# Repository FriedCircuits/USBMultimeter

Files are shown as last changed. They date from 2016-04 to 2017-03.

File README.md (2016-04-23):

USB Multimeter
===============================================

This repo will contain all the design and firmware code for the USB Multimeter as development progresses.

Currently the project is just a add-on board for the STM32F429 Discovery board. See the subfolder for details. 

More information at
[https://hackaday.io/friedcircuits](https://hackaday.io/friedcircuits)

License: All source code and designs are released under 

Creative Commons ShareAlike 

CC BY-SA



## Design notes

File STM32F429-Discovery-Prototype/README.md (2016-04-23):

Prototype Using the STM32F429 Discovery Board
===============================================

This is a add-on board that can be press-fit to the bottom of the STM32F429 Discovery board 
to allow firmware development till I can design the prototype hardware. 

More information at
[https://hackaday.io/friedcircuits](https://hackaday.io/friedcircuits)

License: All source code and designs are released under 

Creative Commons ShareAlike 

CC BY-SA



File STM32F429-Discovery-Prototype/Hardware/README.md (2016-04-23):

Hardware for USB Multimeter STM32F429 Add-on Board
======================================================

Warning: The TX/RX pairs need to be swapped for this design to work.

I only made one spin of this board and ended up swapping the pairs with some bodge wires.

Also there is an I2C address conflict with the INA219's. I forgot to set the 2nd one to another address.

This is here just as a referance as this was a one off board.

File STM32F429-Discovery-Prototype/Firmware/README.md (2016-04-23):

Prototype Using the STM32F429 Discovery Board
===============================================

This the firmware for the Discovery Board. 

Written is C using Embitz IDE.

The firmware is built on top of ChibiOS which has excellent support for STM32.

The graphics engine is handled by uGFX. 

This code is highly alpha with many bugs and crashes. It is a work in progress. 

Eventually this will be turned into the firmware for the final hardare prototype. 

License: All source code and designs are released under 

Creative Commons ShareAlike 

CC BY-SA



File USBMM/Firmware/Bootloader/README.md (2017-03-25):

#USB Multimeter Bootloader
Posted for testing during development
Do not use since USB VID/PID needs to be changed.

Based on fork from 
[https://github.com/watterott/SAM-BAR](https://github.com/watterott/SAM-BAR)

# SAM-BAR
SAM-BAR (**S**mart **A**tmel **M**icrocontroller **B**oot **A**ssistant **R**eloaded) is an USB bootloader for Atmel/Microchip SAM D21 devices (ARM Cortex-M0+).
It is based on the following bootloaders:
* [SAM-BA (AppNote AT07175) by Atmel/Microchip (www.atmel.com)](http://www.atmel.com/images/Atmel-42366-SAM-BA-Bootloader-for-SAM-D21_ApplicationNote_AT07175.zip)
* [Arduino Zero Bootloader by Arduino LLC (www.arduino.cc)](https://github.com/arduino/ArduinoCore-samd/tree/master/bootloaders/zero)
* [SAMD-MSD-Bootloader by Justin Mattair (www.mattairtech.com)](https://github.com/mattairtech/SAMD-MSD-Bootloader)

## Features
* SAM-BA and Arduino Zero compatible Bootloader (USB CDC/VCP)
* Mass-Storage-Device Bootloader (USB MSD/MSC)
* Fits in 16KB (user program start at 0x4000)

## Software
* [Bootloader Source Code](https://github.com/friedcircuits/USBMultimeter/tree/master/USBMM/Firmware/Bootloader/bootloader)
* [Board Support Package for Arduino IDE](https://github.com/friedcircuits/USBMultimeter/tree/master/USBMM/Firmware/Bootloader/arduino)

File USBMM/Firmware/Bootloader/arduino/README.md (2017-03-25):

#USB Multimeter Bootloader
Posted for testing during development
Do not use since USB VID/PID needs to be changed.

# Board Support Package
Board Support Package for [Arduino IDE v1.6+](https://www.arduino.cc/en/Main/Software) with Arduino SAMD Boards v1.6.10+

## Installation

Add the following URL to the Arduino Boards Manager (*File->Preferences*):
```
https://github.com/FriedCircuits/USBMultimeter/raw/master/USBMM/Firmware/Bootloader/arduino/package_usbmm_index.json
```
Then open the Arduino Boards Manager (*Tools->Boards->Boards Manager*) and install the 
**Arduino SAMD Boards** and **SAMD (ARM Cortex-M0+) Boards with SAM-BAR**.

## Bootloader

The bootloader can be activated via the Arduino IDE or by doing two reset in 0.5s (double pressing reset switch).

When the bootloader is active then a new program can be loaded via the Arduino IDE and the serial port or via the mass storage device.
For the mass storage device delete the file ```FLASH.BIN``` and then copy a new binary file ```FLASH.BIN``` to the drive.
After the copy process is finished, do a reset to start the new program.

A binary file can be generated and exported in the Arduino IDE with *Sketch->Export compiled Binary* command.

## Known Issues

### Windows
Sometimes the driver for the USB Bootloader is not loaded correctly.
Check the driver state in the Device Manager, when the Bootloader is active (double press reset).
If you cannot install the driver on Windows 8 or higher then deactivate the [driver signature enforcement](https://learn.sparkfun.com/tutorials/disabling-driver-signature-on-windows-8/disabling-signed-driver-enforcement-on-windows-8).
* [SAM-BAR Driver](https://github.com/watterott/SAM-BAR/raw/master/software/arduino/driver.zip)

### Linux
The Modem Manager detects the Serial Ports (e.g. the USB Bootloader) as a modem and therefore a blacklist rule is needed.
Run one of the commands - depending on your system:

```sudo nano /etc/udev/rules.d/77-mm-usb-device-blacklist.rules```

```sudo nano /lib/udev/rules.d/77-mm-usb-device-blacklist.rules```

and add the following lines to the file:
```
ATTRS{idVendor}=="1D50", ATTRS{idProduct}=="6112", ENV{ID_MM_DEVICE_IGNORE}="1"
ATTRS{idVendor}=="1D50", ATTRS{idProduct}=="6113", ENV{ID_MM_DEVICE_IGNORE}="1"
```

Reload udev rules:
```
sudo udevadm control --reload-rules
```

Or you can also remove the Modem Manager from your system with
```
sudo apt-get uninstall modemmanager
```

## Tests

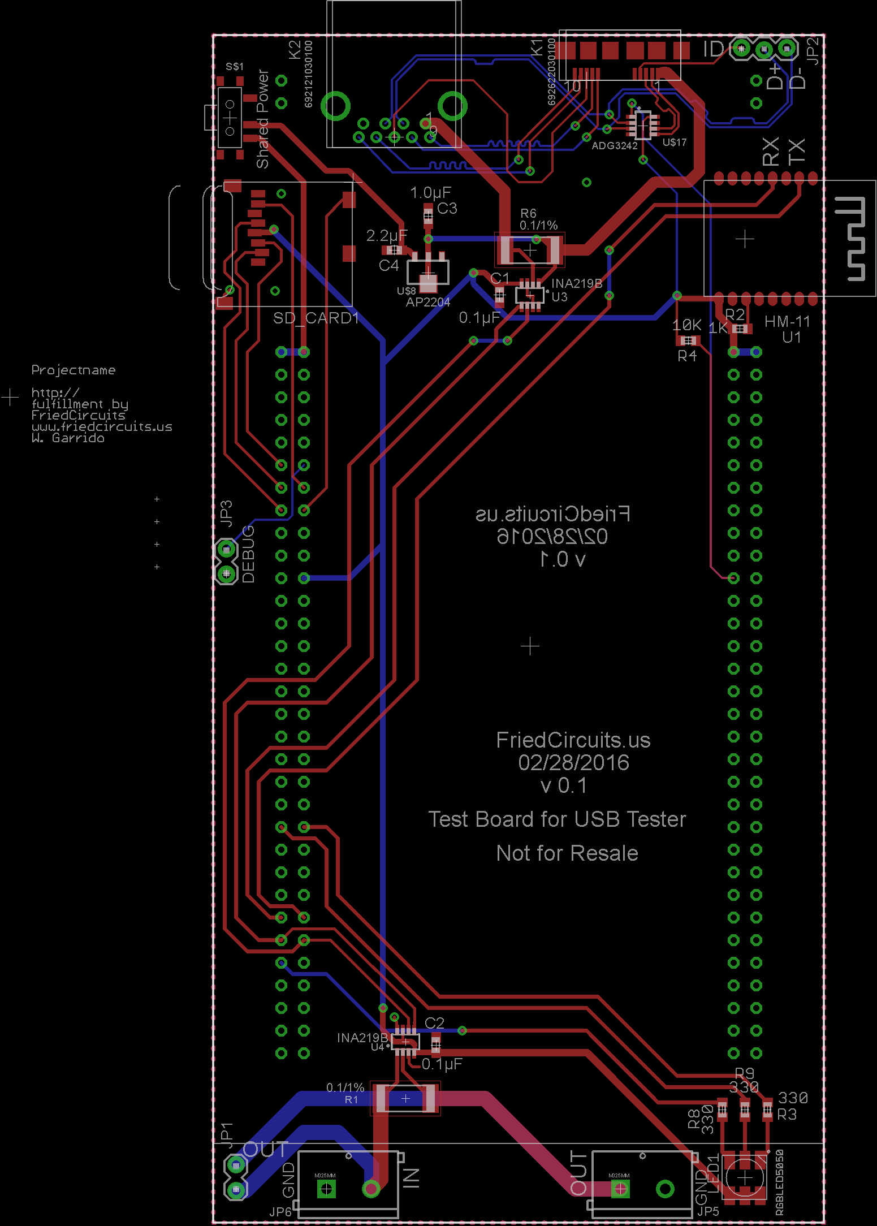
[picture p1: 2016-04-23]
STM32F429-Discovery-Prototype/Hardware/USB_Tester_STM32F429-DISC1-Board.png

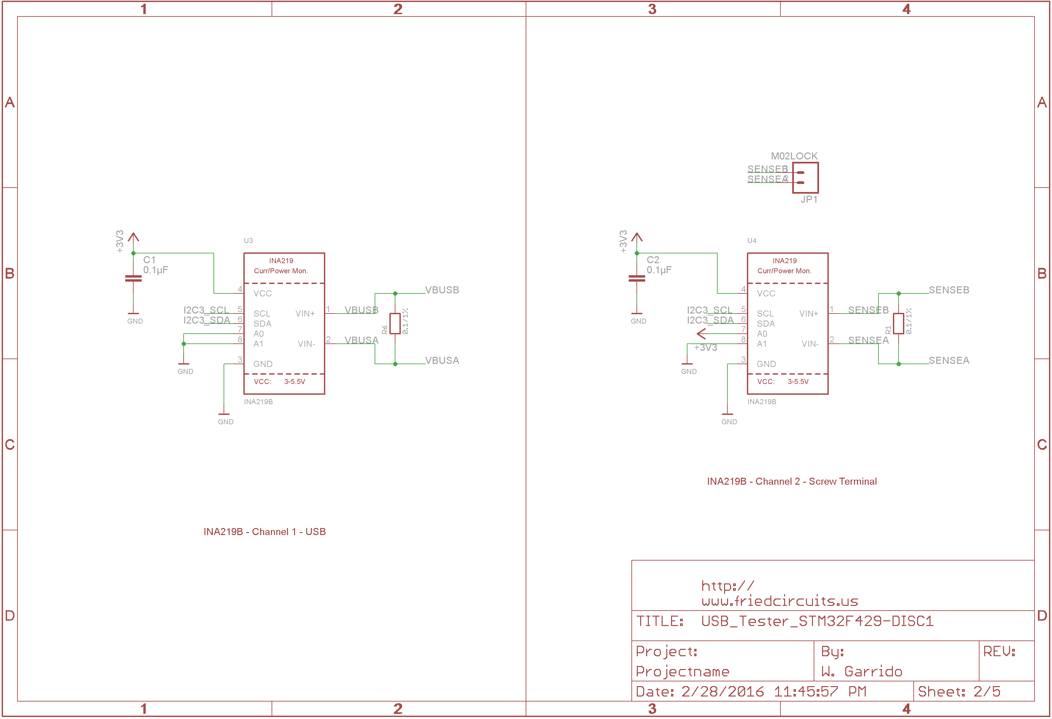
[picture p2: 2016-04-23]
STM32F429-Discovery-Prototype/Hardware/USB_Tester_STM32F429-DISC1-Sch-2.png

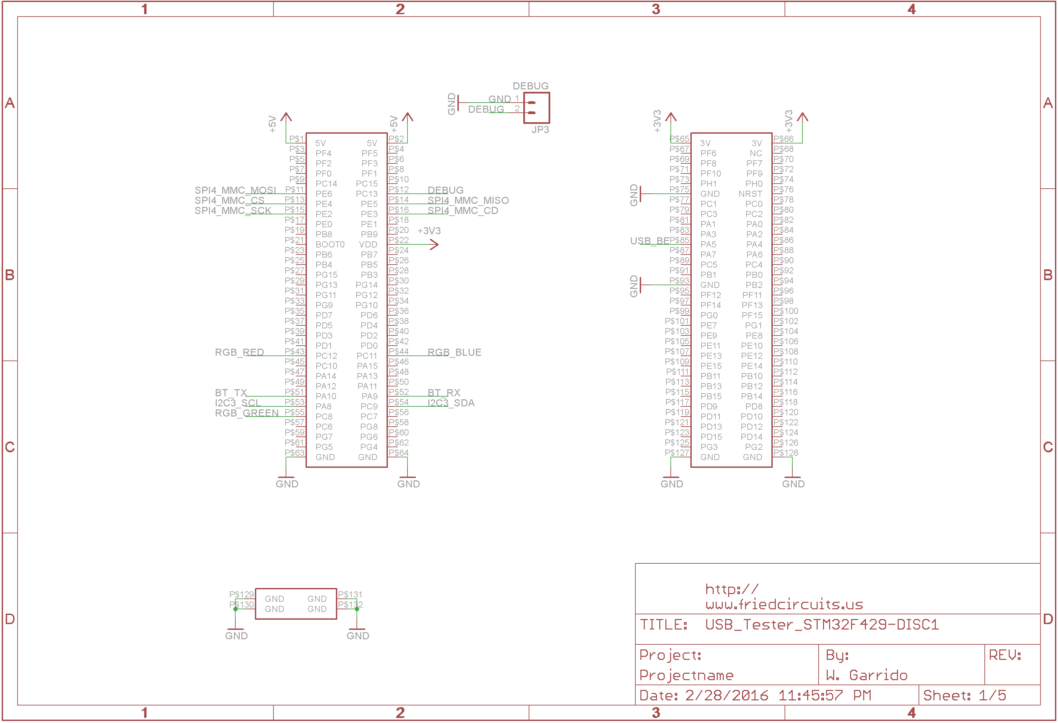
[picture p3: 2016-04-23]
STM32F429-Discovery-Prototype/Hardware/USB_Tester_STM32F429-DISC1-Sch-1.png

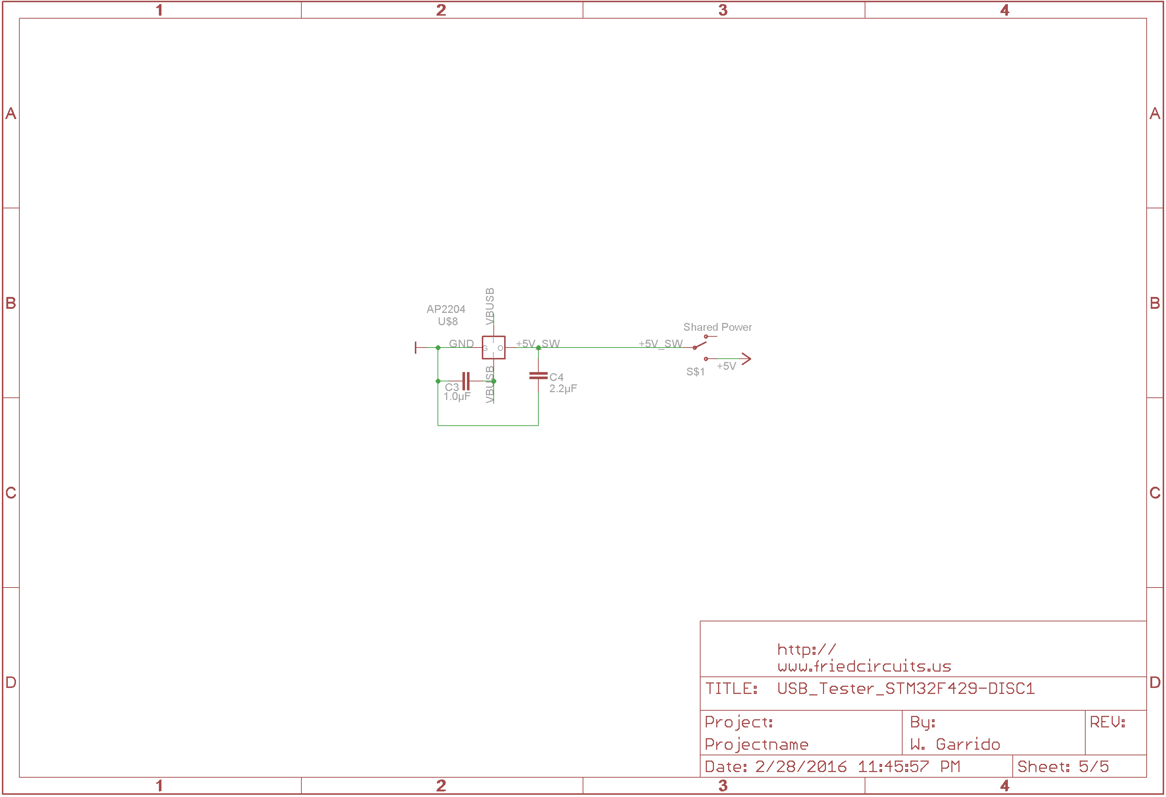
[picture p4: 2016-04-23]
STM32F429-Discovery-Prototype/Hardware/USB_Tester_STM32F429-DISC1-Sch-5.png

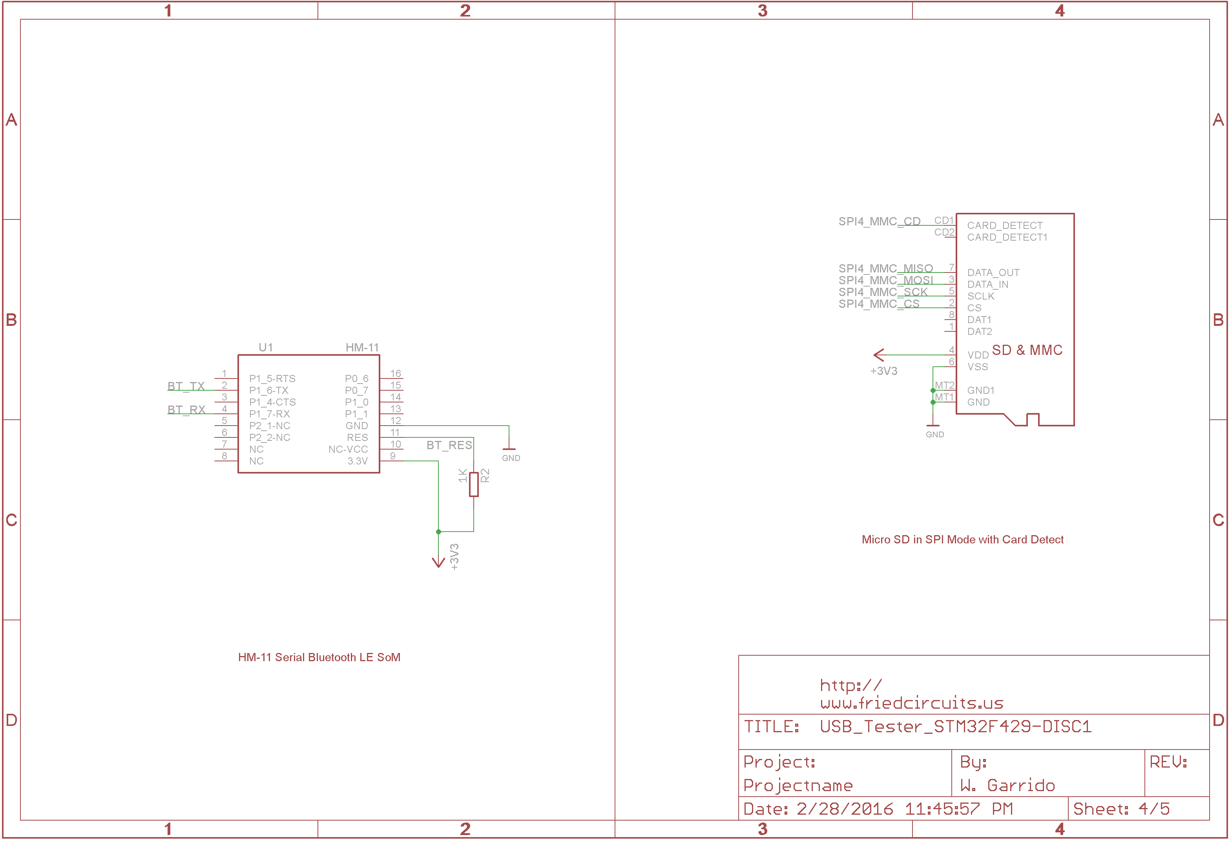
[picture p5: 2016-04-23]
STM32F429-Discovery-Prototype/Hardware/USB_Tester_STM32F429-DISC1-Sch-4.png

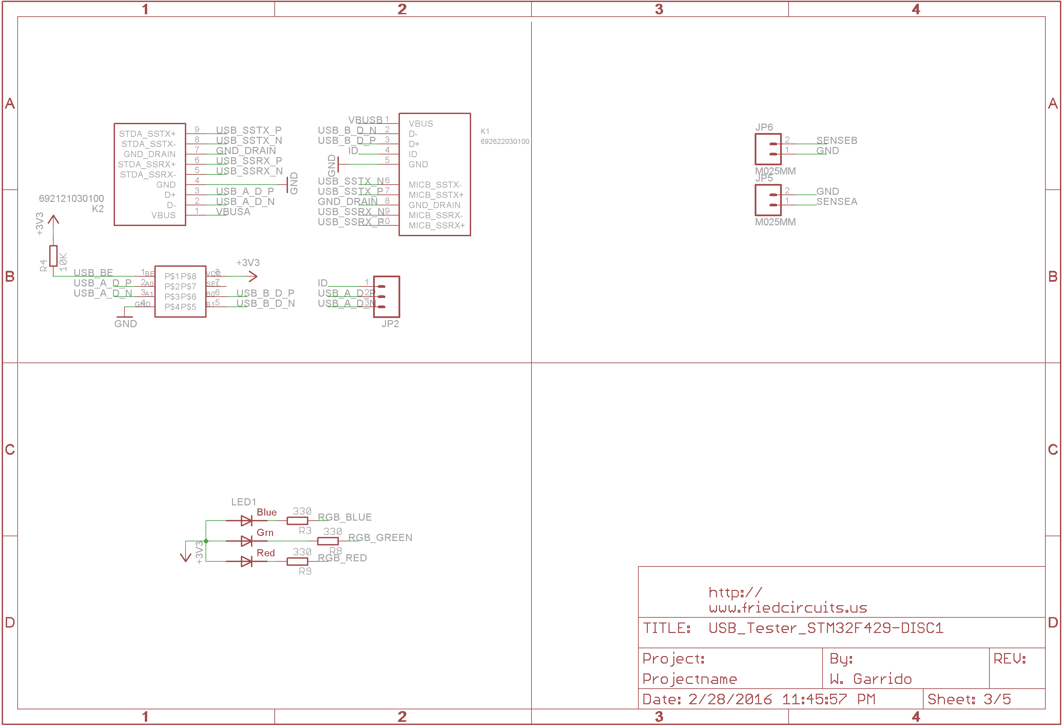
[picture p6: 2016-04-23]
STM32F429-Discovery-Prototype/Hardware/USB_Tester_STM32F429-DISC1-Sch-3.png

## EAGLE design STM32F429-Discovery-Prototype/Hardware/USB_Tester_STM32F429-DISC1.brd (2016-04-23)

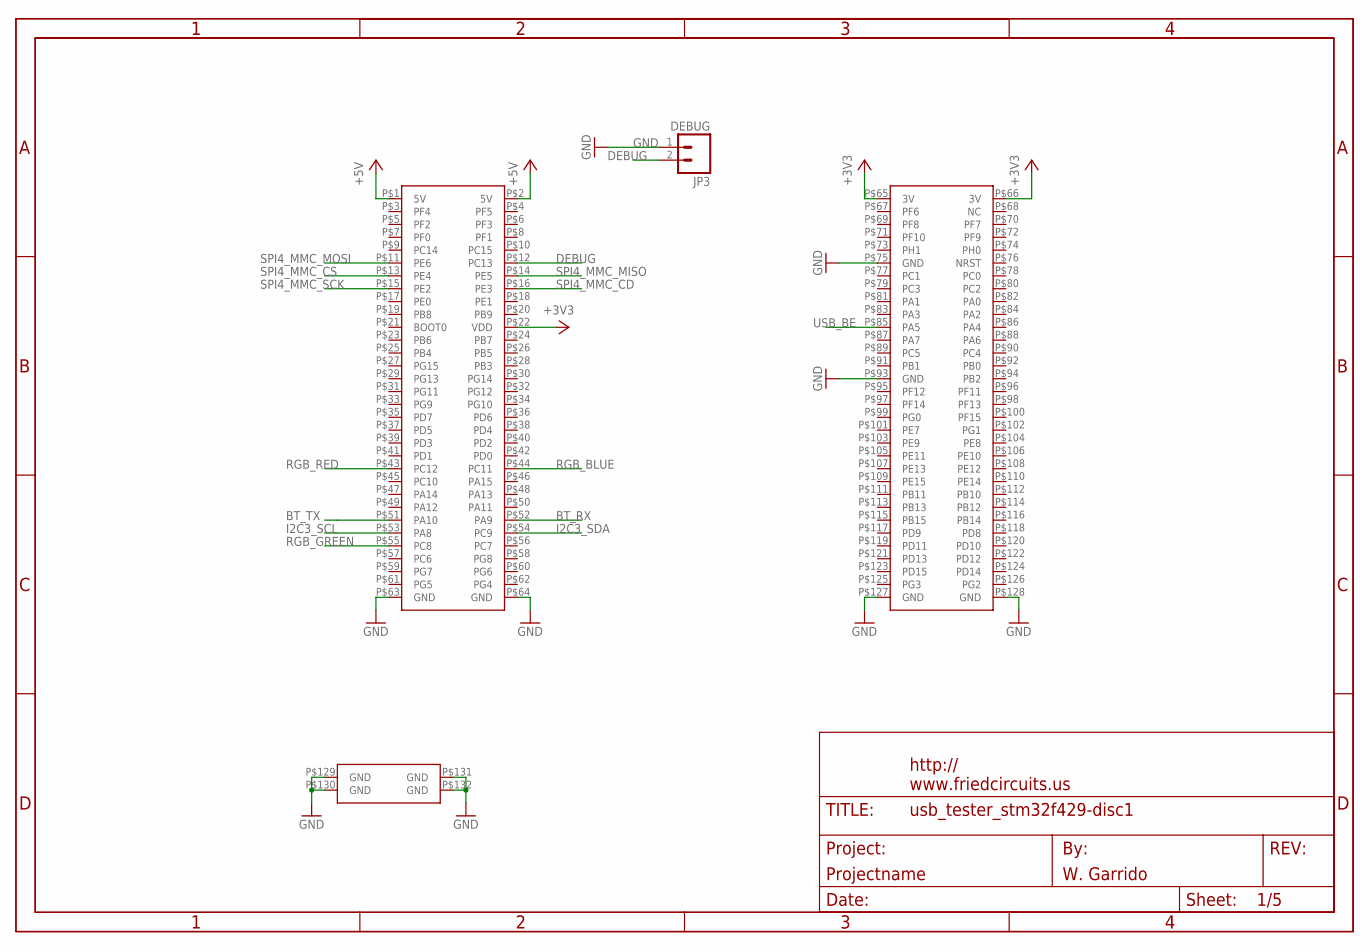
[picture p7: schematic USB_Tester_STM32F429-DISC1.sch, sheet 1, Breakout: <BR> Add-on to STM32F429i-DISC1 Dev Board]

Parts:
JP3: DEBUG; 1X02_LOCK
U$1: STM32F429-DISCO
U$3: FRAME_DINA4_L; FC_CREDIT

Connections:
+3V3: U$1.P$22 (VDD), U$1.P$65 (3V), U$1.P$66 (3V); also elsewhere on the board
+5V: U$1.P$1 (5V), U$1.P$2 (5V); also elsewhere on the board
BT_RX: U$1.P$52 (PA9); also elsewhere on the board
BT_TX: U$1.P$51 (PA10); also elsewhere on the board
DEBUG: JP3.2, U$1.P$12 (PC13)
GND: JP3.1, U$1.P$63 (GND), U$1.P$64 (GND), U$1.P$75 (GND), U$1.P$93 (GND), U$1.P$127 (GND), U$1.P$128 (GND), U$1.P$129 (GND), U$1.P$130 (GND), U$1.P$131 (GND), U$1.P$132 (GND); also elsewhere on the board
I2C3_SCL: U$1.P$53 (PA8); also elsewhere on the board
I2C3_SDA: U$1.P$54 (PC9); also elsewhere on the board
RGB_BLUE: U$1.P$44 (PC11); also elsewhere on the board
RGB_GREEN: U$1.P$55 (PC8); also elsewhere on the board
RGB_RED: U$1.P$43 (PC12); also elsewhere on the board
SPI4_MMC_CD: U$1.P$16 (PE3); also elsewhere on the board
SPI4_MMC_CS: U$1.P$13 (PE4); also elsewhere on the board
SPI4_MMC_MISO: U$1.P$14 (PE5); also elsewhere on the board
SPI4_MMC_MOSI: U$1.P$11 (PE6); also elsewhere on the board
SPI4_MMC_SCK: U$1.P$15 (PE2); also elsewhere on the board
USB_BE: U$1.P$85 (PA5); also elsewhere on the board

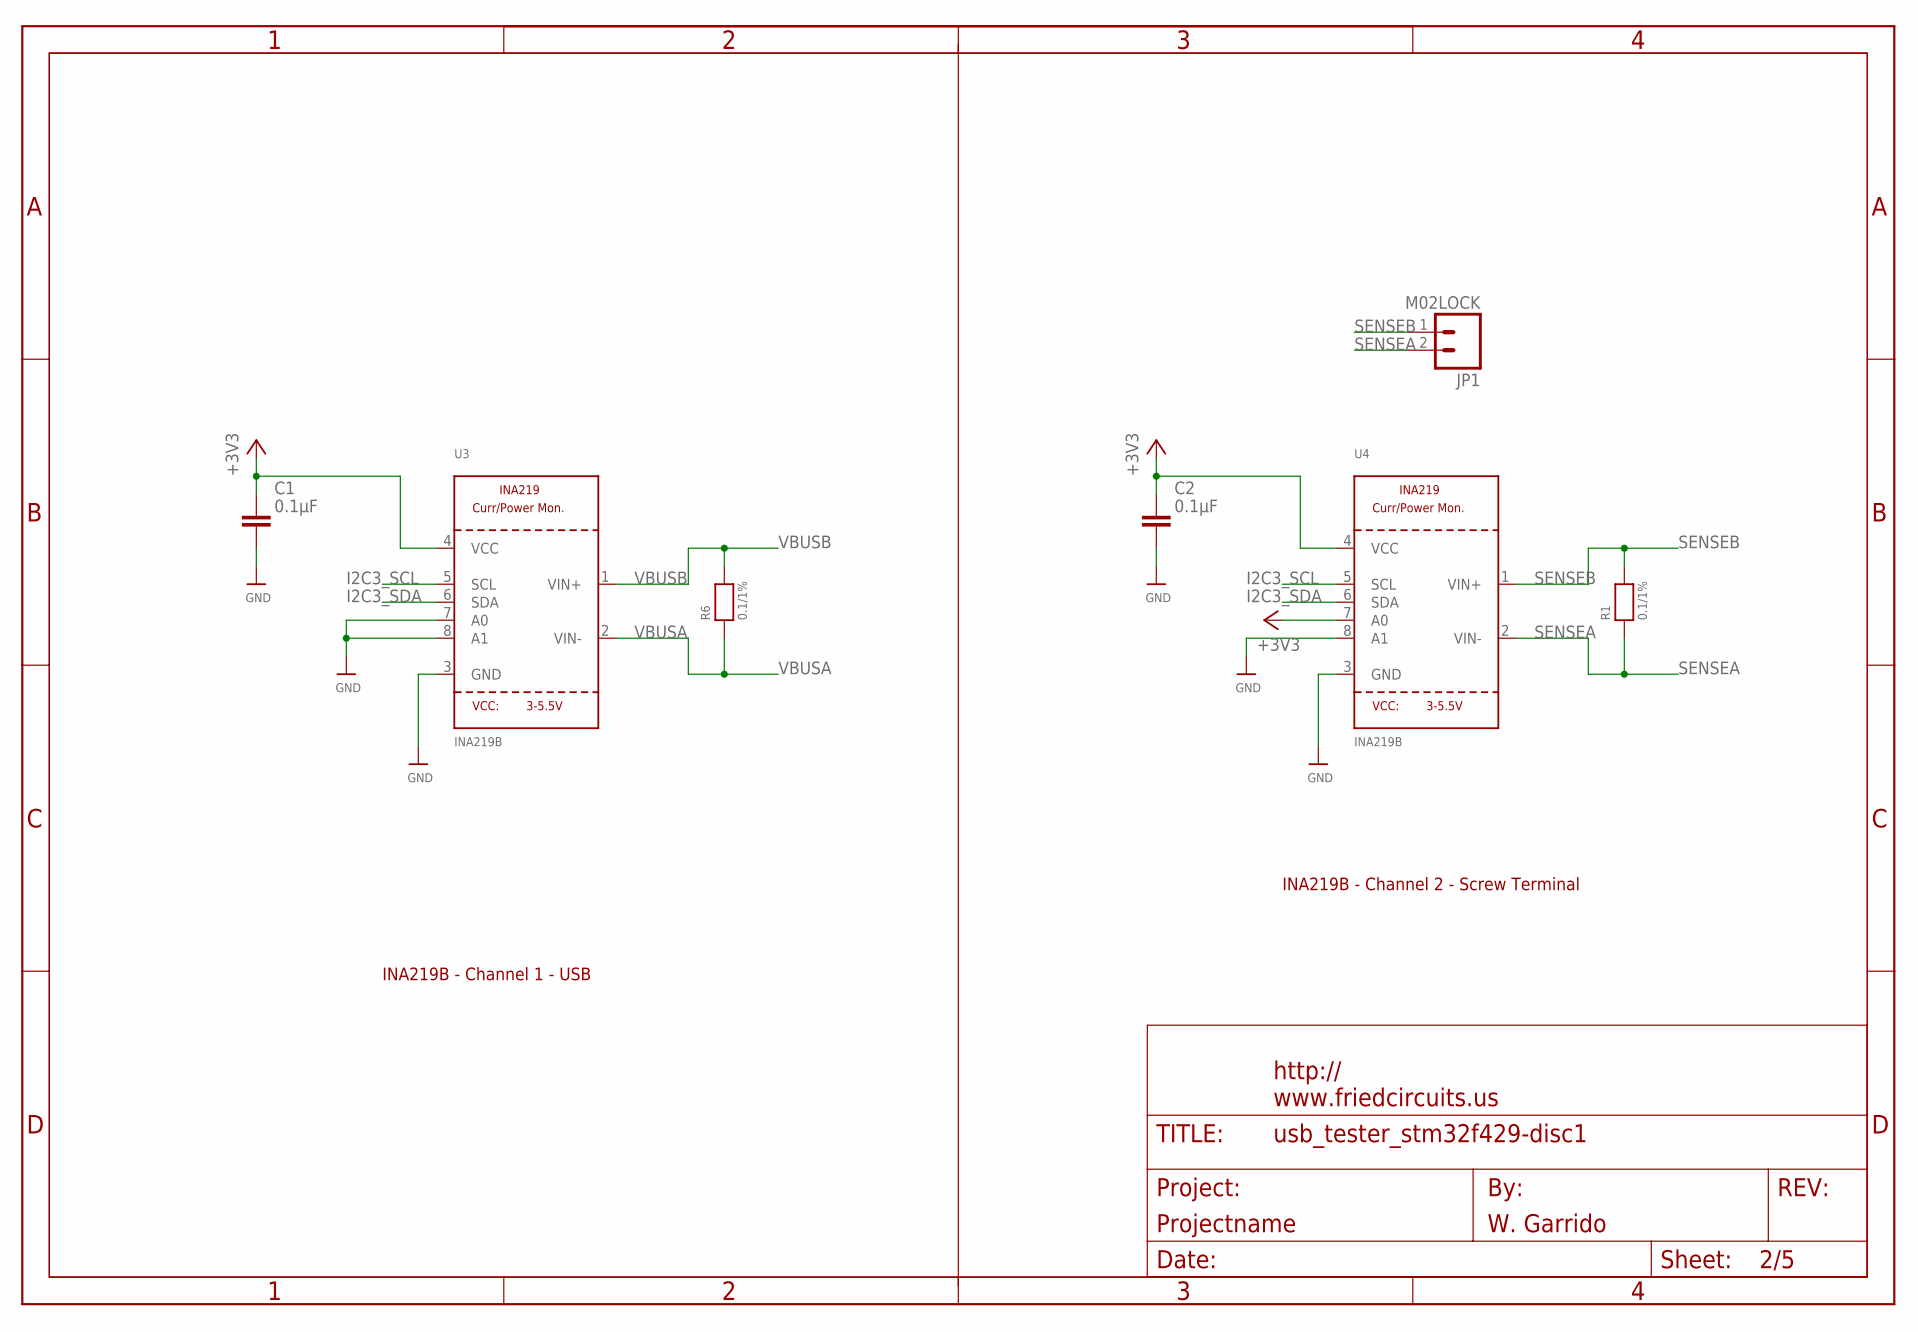
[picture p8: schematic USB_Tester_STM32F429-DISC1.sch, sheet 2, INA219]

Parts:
C1, C2: 0.1µF; C603
JP1: M02LOCK; 1X02_LOCK
R1, R6: 0.1/1%; 2512
U3, U4: INA219B; SOT23-8
U$4: FRAME_DINA4_L; FC_CREDIT

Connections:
+3V3: C1.1, C2.1, U3.4 (VCC), U4.4 (VCC), U4.7 (A0); also elsewhere on the board
GND: C1.2, C2.2, U3.3 (GND), U3.7 (A0), U3.8 (A1), U4.3 (GND), U4.8 (A1); also elsewhere on the board
I2C3_SCL: U3.5 (SCL), U4.5 (SCL); also elsewhere on the board
I2C3_SDA: U3.6 (SDA), U4.6 (SDA); also elsewhere on the board
SENSEA: JP1.2, R1.1, U4.2 (VIN-); also elsewhere on the board
SENSEB: JP1.1, R1.2, U4.1 (VIN+); also elsewhere on the board
VBUSA: R6.1, U3.2 (VIN-); also elsewhere on the board
VBUSB: R6.2, U3.1 (VIN+); also elsewhere on the board

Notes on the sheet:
INA219B - Channel 1 - USB
INA219B - Channel 2 - Screw Terminal

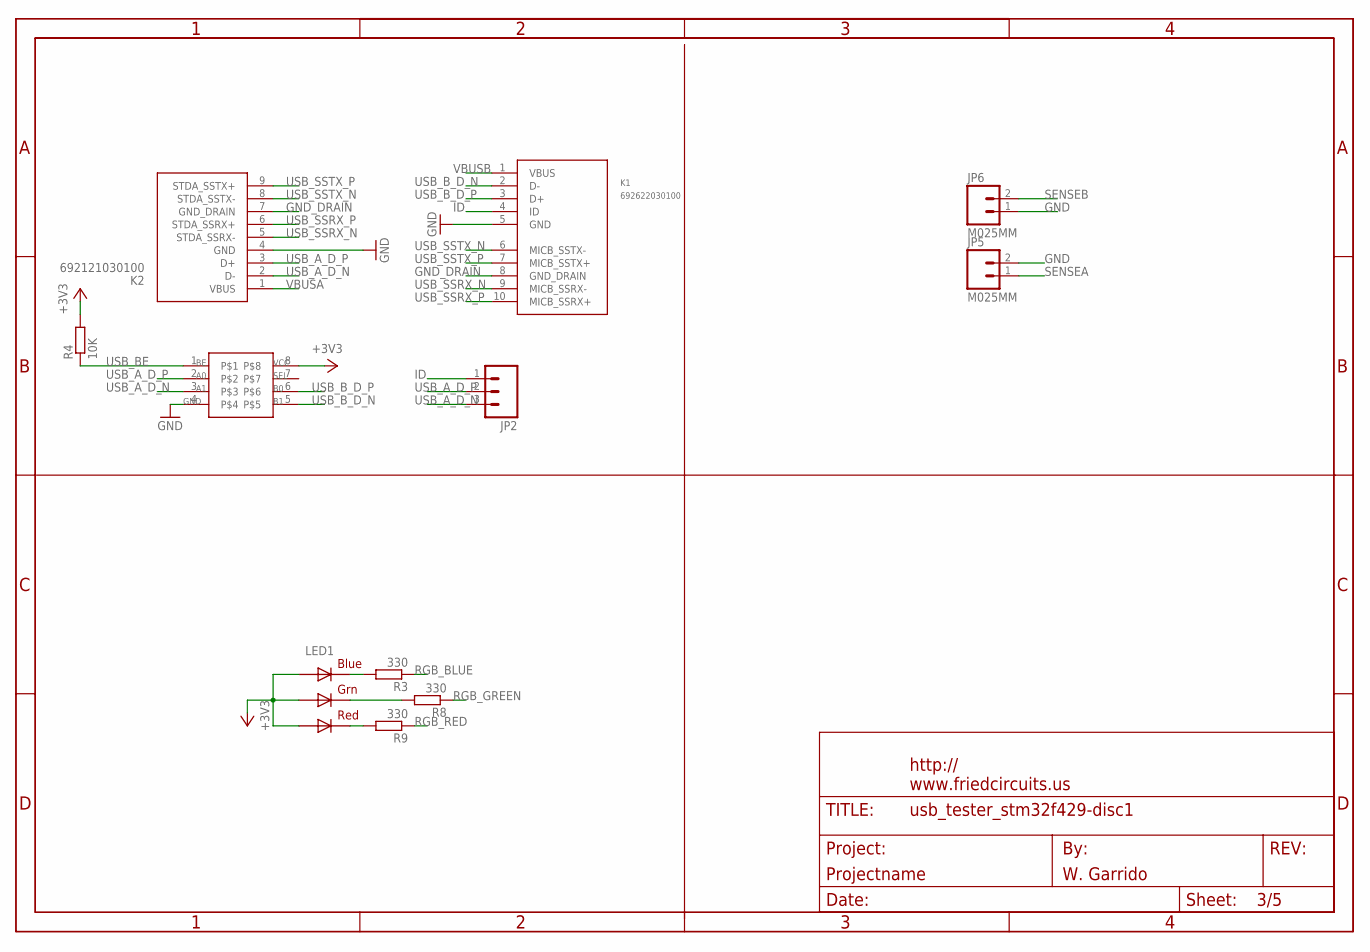
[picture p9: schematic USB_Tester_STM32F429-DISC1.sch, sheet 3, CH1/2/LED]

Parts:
JP2: M03LOCK; 1X03_LOCK
JP5, JP6: M025MM; SCREWTERMINAL-5MM-2
K1: 692622030100
K2: 692121030100
LED1: RGBLED5050
R3, R8, R9: 330; R603
R4: 10K; R603
U$2: FRAME_DINA4_L; FC_CREDIT
U$17: ADG3242; SOT23-8

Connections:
+3V3: LED1.1 (GREEN_A), LED1.2 (RED_A), LED1.3 (BLUE_A), R4.2, U$17.8; also elsewhere on the board
GND: JP5.2, JP6.1, K1.5 (GND), K2.4 (GND), U$17.4; also elsewhere on the board
GND_DRAIN: K1.8 (GND_DRAIN), K2.7 (GND_DRAIN)
ID: JP2.1, K1.4 (ID)
unnamed: LED1.4 (BLUE_C), R3.2
unnamed: LED1.6 (GREEN_C), R8.2
unnamed: LED1.5 (RED_C), R9.2
RGB_BLUE: R3.1; also elsewhere on the board
RGB_GREEN: R8.1; also elsewhere on the board
RGB_RED: R9.1; also elsewhere on the board
SENSEA: JP5.1; also elsewhere on the board
SENSEB: JP6.2; also elsewhere on the board
USB_A_D_N: JP2.3, K2.2 (D-), U$17.3
USB_A_D_P: JP2.2, K2.3 (D+), U$17.2
USB_BE: R4.1, U$17.1; also elsewhere on the board
USB_B_D_N: K1.2 (D-), U$17.5
USB_B_D_P: K1.3 (D+), U$17.6
USB_SSRX_N: K1.9 (MICB_SSRX-), K2.5 (STDA_SSRX-)
USB_SSRX_P: K1.10 (MICB_SSRX+), K2.6 (STDA_SSRX+)
USB_SSTX_N: K1.6 (MICB_SSTX-), K2.8 (STDA_SSTX-)
USB_SSTX_P: K1.7 (MICB_SSTX+), K2.9 (STDA_SSTX+)
VBUSA: K2.1 (VBUS); also elsewhere on the board
VBUSB: K1.1 (VBUS); also elsewhere on the board

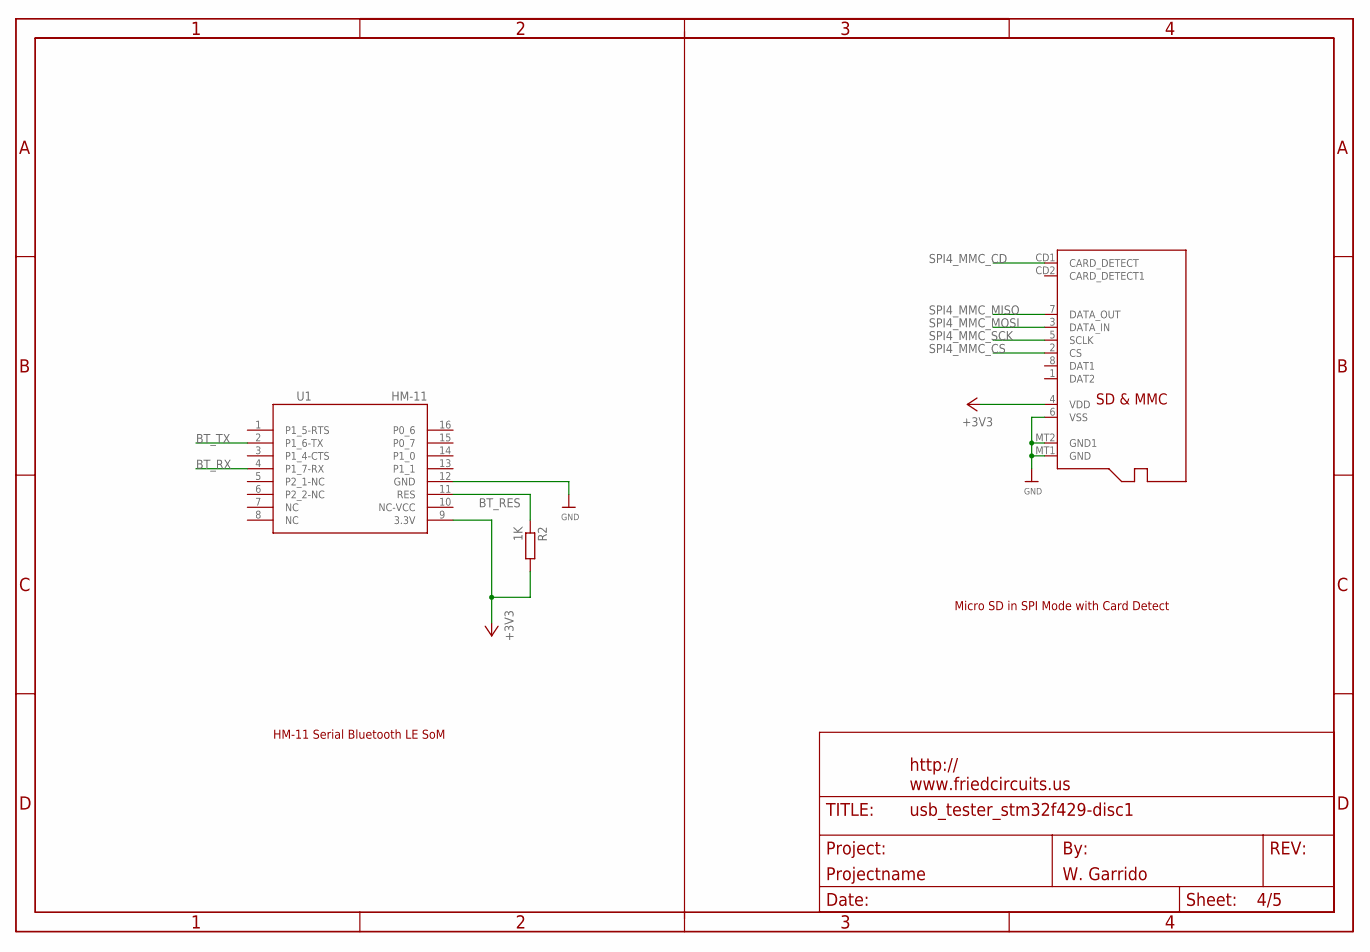
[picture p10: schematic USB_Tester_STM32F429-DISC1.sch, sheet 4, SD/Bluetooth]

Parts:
R2: 1K; R603
SD_CARD1: MICROSD
U1: HM-11
U$5: FRAME_DINA4_L; FC_CREDIT

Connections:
+3V3: R2.2, SD_CARD1.4 (VDD), U1.9 (3.3V); also elsewhere on the board
BT_RES: R2.1, U1.11 (RES)
BT_RX: U1.4 (P1_7-RX); also elsewhere on the board
BT_TX: U1.2 (P1_6-TX); also elsewhere on the board
GND: SD_CARD1.6 (VSS), SD_CARD1.MT1 (GND), SD_CARD1.MT2 (GND1), U1.12 (GND); also elsewhere on the board
SPI4_MMC_CD: SD_CARD1.CD1 (CARD_DETECT); also elsewhere on the board
SPI4_MMC_CS: SD_CARD1.2 (CS); also elsewhere on the board
SPI4_MMC_MISO: SD_CARD1.7 (DATA_OUT); also elsewhere on the board
SPI4_MMC_MOSI: SD_CARD1.3 (DATA_IN); also elsewhere on the board
SPI4_MMC_SCK: SD_CARD1.5 (SCLK); also elsewhere on the board

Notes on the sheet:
HM-11 Serial Bluetooth LE SoM
Micro SD in SPI Mode with Card Detect

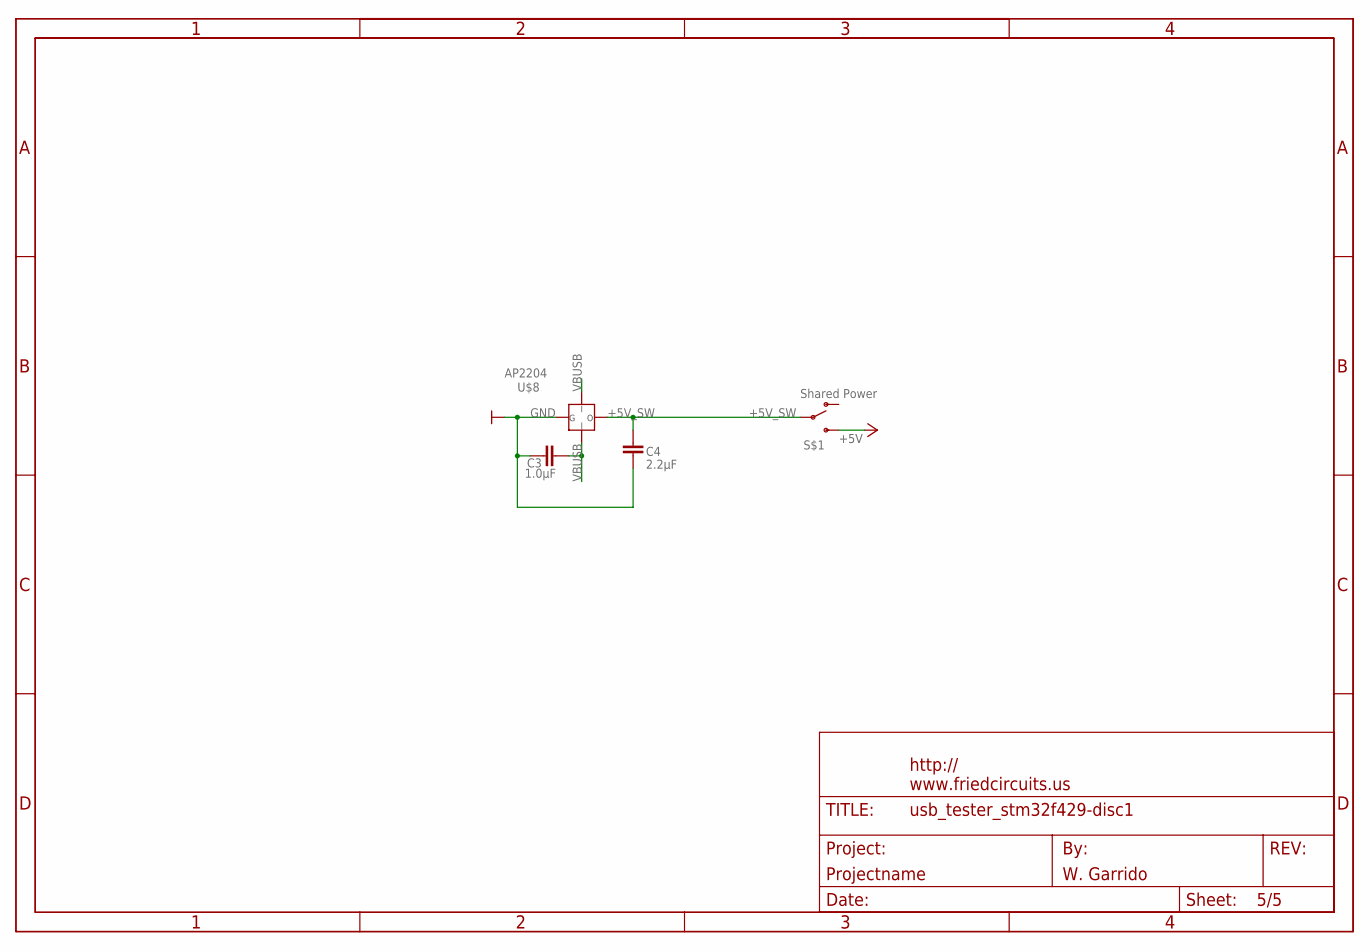
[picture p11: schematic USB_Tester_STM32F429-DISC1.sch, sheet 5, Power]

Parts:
C3: 1.0µF; C603
C4: 2.2µF; C603
S$1: Shared Power; KPS-1290
U$6: FRAME_DINA4_L; FC_CREDIT
U$8: AP2204; SOT89-3

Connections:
+5V: S$1.S; also elsewhere on the board
+5V_SW: C4.1, S$1.P, U$8.3 (O)
GND: C3.2, C4.2, U$8.1 (G); also elsewhere on the board
VBUSB: C3.1, U$8.2 (VIN), U$8.4 (VIN); also elsewhere on the board

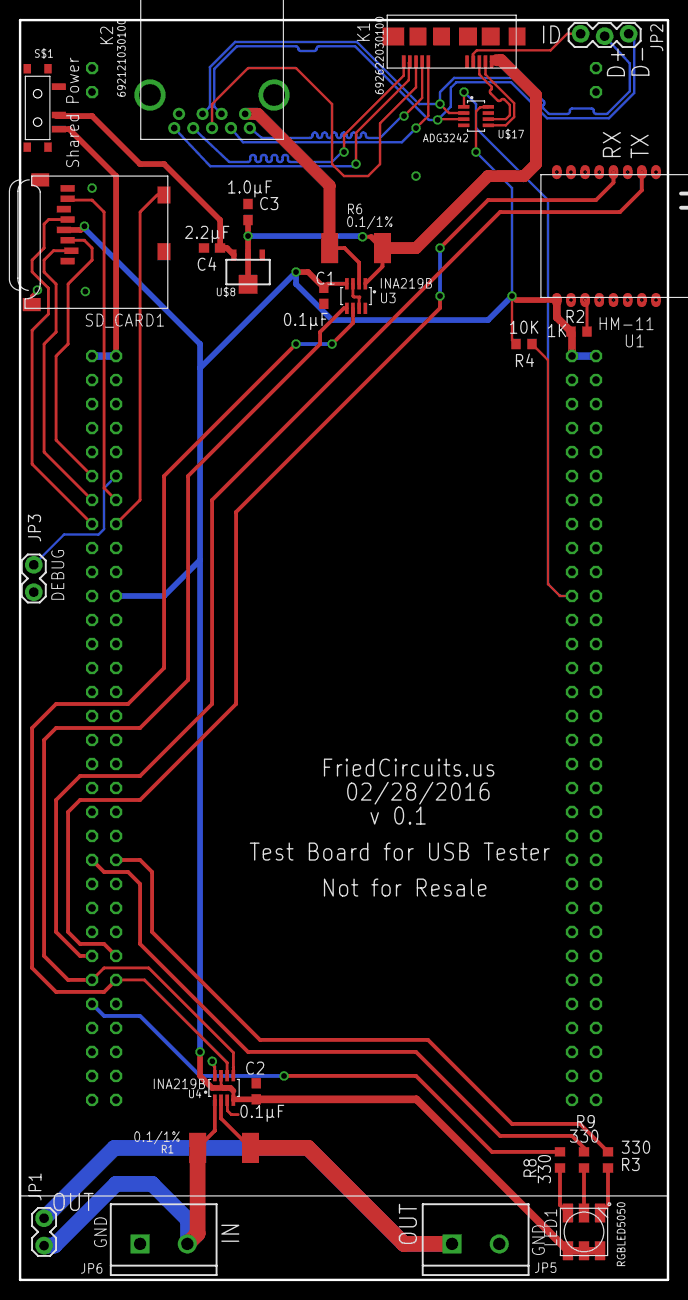
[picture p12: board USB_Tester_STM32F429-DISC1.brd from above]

Board: 2 copper layers, 68.6 x 133.3 mm, 32 parts (0 on the bottom side), 36 nets.

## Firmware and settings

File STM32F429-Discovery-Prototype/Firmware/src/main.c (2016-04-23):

#include "ch.h"
#include "hal.h"
#include "gui.h"
#include "gfx.h"
#include "lib/ina219/ina219.h"
#include "lib/util/stm32_util.h"
#include "usbtester.h"
#include "ff.h"
#include "usbcfg.h"
#include "chprintf.h"
#include "sdcard.h"
#include "cmd.h"
#include "usbdata.h"

// Global variables
bool updateDisplayValues = false;
volatile float shuntvoltage = 0;
volatile float busvoltage = 0;
volatile float current_mA = 0;
volatile float loadvoltage = 0;
volatile float milliwatthours = 0;
volatile float milliamphours = 0;

// Keep track of peak/min significant values:
volatile float peakCurrent = 0;
volatile float voltageAtPeakCurrent = 0;
volatile float minVoltage = 10;
volatile float currentAtMinVoltage = 0;
// (no need, we can compute it) volatile float peakPower = 0;
volatile float voltageAtPeakPower = 0;
volatile float currentAtPeakPower = 0;

// Keep track of variation of volts/amps over the serial refresh period
volatile float rpPeakCurrent = 0;
volatile float rpMinCurrent = 0;
volatile float rpPeakLoadVolt = 0;
volatile float rpMinLoadVolt = 0;
volatile float rpAvgCurrent = 0;
volatile float rpAvgLoadVolt = 0;
uint32_t rpSamples = 1;

// OS Objects
// static virtual_timer_t vtINA;
RTCDateTime timespec;
bool use12HR = false;
bool updateGraph = true;
bool updateSettingTime = false;
struct tm startTime;

// Function prototypes
void startupInit(void);
static void createSettingsFrame(void);
void updateGraphData(float reading, uint8_t graph);
int mapI(int x, int in_min, int in_max, int out_min, int out_max);
float mapf(float x, float in_min, float in_max, float out_min, float out_max);
void setLabelTime(GHandle gh, bool timeDate);
void setStartTime(void);
void drawGraphLines(GHandle gh);
void displayGraph(GHandle gh, uint8_t graph);
void setActiveGraph(uint8_t graph);
void graphInit(void);


static THD_WORKING_AREA(ledThread, 128);
static THD_FUNCTION(ThreadLED, arg)
{
	(void)arg;

	chRegSetThreadName("HeartBeat");

	while (true) {
		palSetPad(GPIOG, GPIOG_LED3_GREEN);
		chThdSleepMilliseconds(100);
		palClearPad(GPIOG, GPIOG_LED3_GREEN);
		chThdSleepMilliseconds(1000);
	}
}

static THD_WORKING_AREA(gfxvalThread, 2048);
static THD_FUNCTION(ThreadGFXVal, arg)
{
	(void)arg;

	chRegSetThreadName("GFXVal");

	while (true) {
		gwinSetText(ghlblV, util_floatToString(loadvoltage, UNIT_V), TRUE);
		gwinSetText(ghlblA, util_floatToString(current_mA, UNIT_MA), TRUE);
		gwinSetText(ghlblW, util_floatToString(((current_mA*loadvoltage)/1000), UNIT_W), TRUE);
		//gwinSetText(ghlblAH, util_floatToString(milliamphours, UNIT_MAH), TRUE);

		if ((scaleChanged) && (activeGraph != 3)) {
			char str[7];
			snprintf(str, 7, "%d%s", autoscale_limits[activeGraph][graph_MAX[activeGraph]], units[graphUnits[activeGraph]]);
			gwinSetText(ghBtnScale, str, TRUE);
			drawGraphLines(ghContainerGraphC);
			scaleChanged = false;
		}

		if (activeGraph == 3) {
			char str[7];
			snprintf(str, 7, "%d%s", autoscale_limits[0][graph_MAX[0]], units[graphUnits[0]]);
			gwinSetText(ghBtnScale, str, TRUE);
			scaleChanged = false;
			snprintf(str, 7, "%d%s", autoscale_limits[1][graph_MAX[1]], units[graphUnits[1]]);
			gwinDrawString(ghContainerGraphCV_2, gwinGetWidth(ghContainerGraphCV_2)-25, 5, str);
			drawGraphLines(ghContainerGraphCV_1);
			drawGraphLines(ghContainerGraphCV_2);
		}

		chThdSleepMilliseconds(500);
	}
}

static THD_WORKING_AREA(graphThread, 2048);
static THD_FUNCTION(ThreadGRAPH, arg)
{
	(void)arg;

	chRegSetThreadName("Graph");

	while (true) {
		updateGraphData(current_mA, 0);
		updateGraphData(loadvoltage, 1);
		updateGraphData(((current_mA*loadvoltage)/1000), 2);

		if (activeGraph == 0) {
			displayGraph(ghContainerGraphC, 0);
		}

		if (activeGraph == 1) {
			displayGraph(ghContainerGraphV, 1);
		}

		if (activeGraph == 2) {
			displayGraph(ghContainerGraphW, 2);
		}

		if (activeGraph == 3) {
			displayGraph(ghContainerGraphCV_1, 0);
			displayGraph(ghContainerGraphCV_2, 1);
		}

		chThdSleepMilliseconds(GRAPH_Refresh);
	}
}


static THD_WORKING_AREA(gfxEventThread, 2048);
static THD_FUNCTION(ThreadGFXEvent, arg)
{
	(void)arg;

	chRegSetThreadName("GFXEvent");

	GEvent* pe;
	static RTCDateTime timespec;
	struct tm timeinfo;
	struct tm tim;
	struct tm *canary;
	static time_t unix_time;
	while (true) {
		pe = geventEventWait(&gl, TIME_INFINITE);
		switch (pe->type) {
			case GEVENT_GWIN_BUTTON:
				if (((GEventGWinButton*)pe)->gwin == ghBtnSettings) {
					createSettingsFrame();
					gwinShow(ghFrame1);
					updateGraph = false;
					updateSettingTime = true;
				} else if (((GEventGWinButton*)pe)->gwin == ghBtnSave) {
					timeinfo.tm_hour = atoi(gwinListGetSelectedText(ghListHour));
					timeinfo.tm_min = atoi(gwinListGetSelectedText(ghListMin));
					timeinfo.tm_sec = 0;
					timeinfo.tm_mday = atoi(gwinListGetSelectedText(ghListDay));
					timeinfo.tm_mon = gwinListGetSelected(ghListMonth);
					timeinfo.tm_year = atoi(gwinListGetSelectedText(ghListYear))-1900;
					unix_time = mktime(&timeinfo);
					canary = localtime_r(&unix_time, &tim);
					osalDbgCheck(&tim == canary);
					rtcConvertStructTmToDateTime(&tim, 0, &timespec);
					rtcSetTime(RTC_DRIVER, &timespec);
				} else if (((GEventGWinButton*)pe)->gwin == ghBtnTime) {
					updateGraph = false;
					gwinShow(ghListFreq);
				}
				break;

			case GEVENT_GWIN_CHECKBOX:
				if (((GEventGWinCheckbox*)pe)->gwin == ghCheckBoxHR) {
					if (((GEventGWinCheckbox*)pe)->isChecked)
						use12HR = true;
					else
						use12HR = false;
				}
				break;

			case GEVENT_GWIN_CLOSE:
				updateGraph = true;
				updateSettingTime = false;
				switch (activeGraph) {
					case 0:
						drawGraphLines(ghContainerGraphC);
						break;

					case 1:
						drawGraphLines(ghContainerGraphV);
						break;

					case 2:
						drawGraphLines(ghContainerGraphW);
						break;

					case 3:
						drawGraphLines(ghContainerGraphCV_1);
						drawGraphLines(ghContainerGraphCV_2);
						break;

					default:
						break;
				}
				break;

			case GEVENT_GWIN_RADIO:
				activeGraph = atoi(gwinGetText(((GEventGWinRadio *)pe)->gwin));
				setActiveGraph(activeGraph);
				break;

			case GEVENT_GWIN_LIST:
				if (((GEventGWinList*)pe)->gwin == ghListFreq)  {
					char str[5];
					uint8_t val = atoi(gwinListGetSelectedText(ghListFreq));
					GRAPH_Refresh = ((1.0/val)*1000);
					snprintf(str, 5, "%d%s", val, "Hz");
					gwinSetText(ghBtnTime, str, true);
					chThdSleepMilliseconds(10);
					gwinHide(ghListFreq);
					updateGraph = true;

					switch (activeGraph) {
					case 0:
						drawGraphLines(ghContainerGraphC);
						break;

					case 1:
						drawGraphLines(ghContainerGraphV);
						break;

					case 2:palSetPadMode(GPIOA, 5, PAL_MODE_OUTPUT_PUSHPULL); palClearPad(GPIOA, 5);
						drawGraphLines(ghContainerGraphW);
						break;

					case 3:
						drawGraphLines(ghContainerGraphCV_1);
						drawGraphLines(ghContainerGraphCV_2);
						break;

					default:
						break;
					}

				}

				break;
			default:
				break;
		}

		chThdSleepMilliseconds(500);
	}
}

static THD_WORKING_AREA(inaThread, 256);
static THD_FUNCTION(ThreadINA, arg)
{
	(void)arg;

	chRegSetThreadName("INA");
	systime_t time = chVTGetSystemTimeX();     // T0

	while (true) {
		time += US2ST(READFREQ);
		//palSetPad(GPIOG, GPIOG_LED4_RED);
		//palTogglePad(GPIOG, GPIOG_LED4_RED);
		busvoltage=ina219GetBusVoltage_V();
		current_mA=ina219GetCurrent_mA();
		shuntvoltage = ina219GetShuntVoltage_mV();
		loadvoltage = busvoltage + (shuntvoltage / 1000);
		milliwatthours += busvoltage*current_mA*READFREQ/1e6/3600; // 1 Wh = 3600 joules
		milliamphours += current_mA*READFREQ/1e6/3600;

		// Update peaks, min and avg during our serial refresh period:
		if (current_mA > rpPeakCurrent)
			rpPeakCurrent = current_mA;
		if (current_mA < rpMinCurrent)
			rpMinCurrent = current_mA;
		if (loadvoltage > rpPeakLoadVolt)
			rpPeakLoadVolt  = loadvoltage;
		if (loadvoltage < rpMinLoadVolt)
			rpMinLoadVolt = loadvoltage;
		rpAvgCurrent = (rpAvgCurrent*rpSamples + current_mA)/(rpSamples+1);
		rpAvgLoadVolt = (rpAvgLoadVolt*rpSamples + loadvoltage)/(rpSamples+1);
		rpSamples++;

		// Update absolute peaks and mins
		if (current_mA > peakCurrent) {
			peakCurrent = current_mA;
			voltageAtPeakCurrent = loadvoltage;
		}

		if (loadvoltage < minVoltage) {
			minVoltage = loadvoltage;palSetPadMode(GPIOA, 5, PAL_MODE_OUTPUT_PUSHPULL); palClearPad(GPIOA, 5);
			currentAtMinVoltage = current_mA;
		}

		//palClearPad(GPIOG, GPIOG_LED4_RED);
		chThdSleepUntil(time);
	}
}

static THD_WORKING_AREA(timeThread, 1024);
static THD_FUNCTION(ThreadTIME, arg)
{
	(void)arg;

	chRegSetThreadName("Time");
	struct tm timp;
	char str_date[100];

	while (true) {
		if(updateSettingTime) {
			setLabelTime(ghlblDateTime, true);
		}

		rtcGetTime(RTC_DRIVER, &timespec);
		rtcConvertDateTimeToStructTm(&timespec, &timp,0);
		//https://www.iar.com/support/resources/articles/using-c-standard-library-time-and-clock-functions/
		//http://www.cplusplus.com/forum/general/57329/
		int timeElap = difftime(mktime(&timp),mktime(&startTime));
		uint8_t hour = timeElap/3600;
		uint16_t second = timeElap % 3600;
		uint8_t minute = second/60;
		second %= 60;
		//timp.tm_sec = second;
		//timp.tm_min = minute;
		//timp.tm_hour = hour;
		//strftime(str_date, sizeof(str_date), "%X", &timp); //%x for date http://www.tutorialspoint.com/c_standard_library/c_function_strftime.htm
		snprintf(str_date, 9, "%02d:%02d:%02d", hour, minute, second);
		gwinSetText(ghlblElapsed, str_date, TRUE);
		chThdSleepMilliseconds(1000);
	}
}

int main(void)
{
	// Initialize ChibiOS
	halInit();
	chSysInit();

	// Initialize uGFX
	gfxInit();

	// Initialize our own stuff
	startupInit();

	// Get the command prompt (via USB) up and running
	cmdCreate();

	// Get the SD-Card stuff done
	sdcardInit();

	while (true) {
        cmdManage();
		if(SDU1.config->usbp->state == USB_ACTIVE){
			gwinShow(ghImageUSB);
		} else {
			gwinHide(ghImageUSB);
		}

		// Until the statusbar widget is ready...
		gwinSetVisible(ghImageSDC, sdcardReady());

        sdCardEvent();

		chThdSleepMilliseconds(500);
	}
}

void startupInit()
{
    usbdataEnable();

	gdispSetBacklight(50);
	gdispSetContrast(50);

	geventListenerInit(&gl);
	gwinAttachListener(&gl);

	// Setup UI objects and show splash
	guiCreate();
	gwinProgressbarSetResolution(ghProgbarLoad, 10);
	gwinProgressbarStart(ghProgbarLoad, 300);
	graphInit();

	// Setup INA219 I2C Current Sensor
	ina219Init();

	sduObjectInit(USB_SERIAL_DRIVER);
	sduStart(USB_SERIAL_DRIVER, &serusbcfg);

	/*
	 * Activates the USB driver and then the USB bus pull-up on D+.
	 * Note, a delay is inserted in order to not have to disconnect the cable
	 * after a reset.
	 */
	usbDisconnectBus(serusbcfg.usbp);
	chThdSleepMilliseconds(1000);
	usbStart(serusbcfg.usbp, &usbcfg);
	usbConnectBus(serusbcfg.usbp);

	setStartTime();

	chThdCreateStatic(ledThread, sizeof(ledThread), LOWPRIO, ThreadLED, NULL);
	chThdCreateStatic(inaThread, sizeof(inaThread), HIGHPRIO, ThreadINA, NULL);
	chThdCreateStatic(gfxvalThread, sizeof(gfxvalThread), NORMALPRIO, ThreadGFXVal, NULL);
	chThdCreateStatic(timeThread, sizeof(timeThread), NORMALPRIO, ThreadTIME, NULL);
	chThdCreateStatic(gfxEventThread, sizeof(gfxEventThread), NORMALPRIO, ThreadGFXEvent, NULL);

	chThdSleepMilliseconds(2000);

	chThdCreateStatic(graphThread, sizeof(graphThread), NORMALPRIO+5, ThreadGRAPH, NULL);
	// Destroy splay screen and show main page
	gwinDestroy(ghContainerPageSplash);
	guiShowPage(1);
}

static void createSettingsFrame(void)
{
	GWidgetInit wi;

	gwinWidgetClearInit(&wi);
	wi.g.show = FALSE;

	wi.g.width = 320;
	wi.g.height = 190;
	wi.g.y = 25;
	wi.g.x = 0;
	wi.text = "Settings";
	ghFrame1 = gwinFrameCreate(0, &wi, GWIN_FRAME_CLOSE_BTN);// | GWIN_FRAME_MINMAX_BTN);

	// Apply some default values for GWIN
	wi.customDraw = 0;
	wi.customParam = 0;
	wi.customStyle = 0;
	wi.g.show = true;

	// Apply the list parameters
	wi.g.width = 65;
	wi.g.height = 50;
	wi.g.y = 10;
	wi.g.x = 10;
	wi.text = "Month";
	wi.g.parent = ghFrame1;

	// Create the actual list
	ghListMonth = gwinListCreate(NULL, &wi, FALSE);
	char item[20];
	int i = 0;
	for (i = 0; i < 12; i++) {
		sprintf(item, "%s", months[i]);
		gwinListAddItem(ghListMonth, item, true);
	}
	gwinListSetScroll(ghListMonth, scrollSmooth);

	// Apply some default values for GWIN
	wi.customDraw = 0;
	wi.customParam = 0;
	wi.customStyle = 0;
	wi.g.show = true;

	// Apply the list parameters
	wi.g.width = 25;
	wi.g.height = 50;
	wi.g.y = 10;
	wi.g.x = 80;
	wi.text = "Day";
	wi.g.parent = ghFrame1;

	// Create the actual list
	ghListDay = gwinListCreate(NULL, &wi, FALSE);
	for (i = 1; i <= 31; i++) {
		sprintf(item, "%i", i);
		gwinListAddItem(ghListDay, item, true);
	}
	gwinListSetScroll(ghListDay, scrollSmooth);

	// Apply some default values for GWIN
	wi.customDraw = 0;
	wi.customParam = 0;
	wi.customStyle = 0;
	wi.g.show = true;

	// Apply the list parameters
	wi.g.width = 45;
	wi.g.height = 50;
	wi.g.y = 10;
	wi.g.x = 110;
	wi.text = "Year";
	wi.g.parent = ghFrame1;

	// Create the actual list
	ghListYear = gwinListCreate(NULL, &wi, FALSE);
	for (i = 2016; i <= 2030; i++) {
		sprintf(item, "%i", i);
		gwinListAddItem(ghListYear, item, true);
	}
	gwinListSetScroll(ghListYear, scrollSmooth);

	wi.g.width = 25;
	wi.g.height = 50;
	wi.g.y = 10;
	wi.g.x = 160;
	wi.text = "Hour";
	wi.g.parent = ghFrame1;

	// Create the actual list
	ghListHour = gwinListCreate(NULL, &wi, FALSE);
	for (i = 1; i <= 24; i++) {
		sprintf(item, "%i", i);
		gwinListAddItem(ghListHour, item, true);
	}
	gwinListSetScroll(ghListHour, scrollSmooth);

	wi.g.width = 25;
	wi.g.height = 50;
	wi.g.y = 10;
	wi.g.x = 190;
	wi.text = "Min";
	wi.g.parent = ghFrame1;

	// Create the actual list
	ghListMin = gwinListCreate(NULL, &wi, FALSE);
	for (i = 1; i <= 60; i++) {
		sprintf(item, "%i", i);
		gwinListAddItem(ghListMin, item, true);
	}
	gwinListSetScroll(ghListMin, scrollSmooth);

	// create Slider1
	wi.g.y = 10; wi.g.x = 235; wi.g.width = 20; wi.g.height = 100; wi.text = "B";
	wi.g.parent = ghFrame1;
	ghSliderBl = gwinSliderCreate(NULL, &wi);

	// create Slider2
	wi.g.y = 10; wi.g.x = 260; wi.g.width = 20; wi.g.height = 100; wi.text = "C";
	wi.g.parent = ghFrame1;
	ghSliderCt = gwinSliderCreate(NULL, &wi);

	// Apply the checkbox parameters
	wi.g.width = 60;        // includes text
	wi.g.height = 20;
	wi.g.y = 75;
	wi.g.x = 10;
	wi.text = " 12 Hr";
	ghCheckBoxHR = gwinCheckboxCreate(NULL, &wi);

	// create button widget: ghBtnSettings
	wi.g.show = TRUE;
	wi.g.x = 235;
	wi.g.y = 130;
	wi.g.width = 50;
	wi.g.height = 27;
	wi.g.parent = ghFrame1;
	wi.text = "Save";
	wi.customDraw = gwinButtonDraw_Rounded;
	//wi.customParam = &iconSettings;
	//wi.customStyle = &WhiteWidgetStyle;
	ghBtnSave = gwinButtonCreate(0, &wi);
	gwinSetFont(ghBtnSave, dejavu_sans_16_anti_aliased_u);

	// Create label widget: ghlblDateTime
	wi.g.show = TRUE;
	wi.g.x = 75;
	wi.g.y = 75;
	wi.g.width = 150;
	wi.g.height = 17;
	wi.g.parent = ghFrame1;
	wi.text = "00/00/00 00:00:00";
	wi.customDraw = gwinLabelDrawJustifiedLeft;
	wi.customParam = 0;
	//wi.customStyle = &syBar;
	ghlblDateTime = gwinLabelCreate(0, &wi);
	gwinLabelSetBorder(ghlblDateTime, FALSE);
	gwinSetFont(ghlblDateTime, dejavu_sans_16_anti_aliased_u);
	gwinRedraw(ghlblDateTime);
}

// Draw the complete graph. This is also where we update the ring
// buffer for graph values
void updateGraphData(float reading, uint8_t graph)
{
	// Adjust scale: we have GRAPH_MEMORY points, so whenever
	// we cross a scale boundary, we initiate a countdown timer.
	// This timer goes down at each redraw if we're under the previous lower scale
	// boundary, otherwise it is reset. If we stay below the scale boundary until it
	// reaches zero, then we scale down.

	if (reading > autoscale_limits[graph][graph_MAX[graph]]) {
		// We need to scale up:
		while (reading > autoscale_limits[graph][graph_MAX[graph]]) {
		  graph_MAX[graph]++;
		  if (graph_MAX[graph] == autoscale_size[graph]-1)
			break;
		  }
		autoscale_countdown[graph] = GRAPH_MEMORY;
		autoscale_max_reading[graph] = 0;
		scaleChanged = true;
		// Let user know the values just got rescaled
		//display.setPrintPos(122,7);
		//display.print("*");
		//delay(100);
	} else if (graph_MAX[graph] > 0) {
		// Do we need to scale down ?
		if (reading < autoscale_limits[graph][graph_MAX[graph]-1]) {
			autoscale_countdown[graph]--; // If we are below the lower scale
			// Keep track of max value of reading during the time we're under current
			// scale limit, so that when we scale down, we go to the correct scale
			// value right away:
			if (reading > autoscale_max_reading[graph])
				autoscale_max_reading[graph] = reading;
			if (autoscale_countdown[graph] == 0) {
				// Time to scale down:
				while (autoscale_max_reading[graph] < autoscale_limits[graph][graph_MAX[graph]-1]) {
					graph_MAX[graph]--;
					if (graph_MAX[graph] == 0) {
						break;
					}
				}

				autoscale_countdown[graph] = GRAPH_MEMORY;
				autoscale_max_reading[graph] = 0;
				scaleChanged = true;
				// Let user know the values just got rescaled
				//display.setPrintPos(122,7);
				//display.print("*");
				//delay(100);
			}
		} else {
			autoscale_countdown[graph] = GRAPH_MEMORY; // we are above the scale under us
			autoscale_max_reading[graph] = 0;
		}
	}
	graph_Mem[graph][ring_idx[graph]] = /*(uint16_t)*/ reading;
	ring_idx[graph] = (ring_idx[graph]+1)%GRAPH_MEMORY;
}


int mapI(int x, int in_min, int in_max, int out_min, int out_max)
{
	return (x - in_min) * (out_max - out_min) / (in_max - in_min) + out_min;
}


float mapf(float x, float in_min, float in_max, float out_min, float out_max)
{
	return (x - in_min) * (out_max - out_min) / (in_max - in_min) + out_min;
}


void setLabelTime(GHandle gh, bool timeDate)
{
	struct tm timp;
	char str_date[100];

	rtcGetTime(RTC_DRIVER, &timespec);
	rtcConvertDateTimeToStructTm(&timespec, &timp,0);
	if (timeDate) {
		if(use12HR)
			strftime(str_date, sizeof(str_date), "%x-%r", &timp);
		else
			strftime(str_date, sizeof(str_date), "%x-%X", &timp); //%x for date http://www.tutorialspoint.com/c_standard_library/c_function_strftime.htm

		//chprintf((BaseSequentialStream*)USB_SERIAL_DRIVER, "%s\r\n", str_date);
		gwinSetText(gh, str_date, TRUE);
	} else {
		if(use12HR)
			strftime(str_date, sizeof(str_date), "%r", &timp);
		else
			strftime(str_date, sizeof(str_date), "%X", &timp);

		gwinSetText(gh, str_date, TRUE);
	}
}

void setStartTime(void)
{
	rtcGetTime(RTC_DRIVER, &timespec);
	rtcConvertDateTimeToStructTm(&timespec, &startTime,0);
}

void drawGraphLines(GHandle gh)
{
	 //color_t oldColor;
	 //oldColor = gh->color;
//     gh->color=White;
//     //Vertical Line
//     gwinDrawLine(gh, 5,0, 5,gwinGetHeight(gh));
//     gwinDrawLine(gh, 0,(gwinGetHeight(gh)/2)-5, 5,(gwinGetHeight(gh)/2)-5); //half way tick
//     gwinDrawLine(gh, 3,(gwinGetHeight(gh)/4)-5, 5,(gwinGetHeight(gh)/4)-5); //qtr ticks
//     gwinDrawLine(gh, 3,((gwinGetHeight(gh)/4)*3)-5, 5,((gwinGetHeight(gh)/4)*3)-5); //qtr ticks
//     gwinDrawLine(gh, 0,0, 5,0); //top end
//     //Horizontal Line
//     gwinDrawLine(gh, 0,gwinGetHeight(gh)-5, gwinGetWidth(gh),gwinGetHeight(gh)-5);
//     gwinDrawLine(gh, (gwinGetWidth(gh)/2)+5, gwinGetHeight(gh)-5, (gwinGetWidth(gh)/2)+5, gwinGetHeight(gh)); //half way tickhttps://www.google.com/webhp?hl=en
//     gwinDrawLine(gh, (gwinGetWidth(gh)/4)+5, gwinGetHeight(gh)-5, (gwinGetWidth(gh)/4)+5, gwinGetHeight(gh)-3); //qtr tick
//     gwinDrawLine(gh, ((gwinGetWidth(gh)/4)*3)+5, gwinGetHeight(gh)-5, ((gwinGetWidth(gh)/4)*3)+5, gwinGetHeight(gh)-3); //qtr way tick
//     gwinDrawLine(gh, gwinGetWidth(gh)-1, gwinGetHeight(gh)-5, gwinGetWidth(gh)-1, gwinGetHeight(gh)); //bottom end

	coord_t i, j;
	color_t r,g,b;
	coord_t width = gwinGetWidth(gh);
	coord_t height = gwinGetHeight(gh);

	for (i = 0; i < width; i++) {
	   for(j = 0; j < height; j++) {
		   //r = ((((_acgraphH[i+(j*width)] >> 11) & 0x1F)*527)+23) >> 6;
		   //g = ((((_acgraphH[i+(j*width)] >> 5) & 0x3f)*259)+33) >> 6;
		   //b = (((_acgraphH[i+(j*width)])  & 0x1f) + 23) >> 6;
		   if (activeGraph == 3 || gh->parent == ghContainerGraphCV) {
			   r = RED_OF(_acgraphH2[i+(j*width)] >> 11);
			   g = GREEN_OF(_acgraphH2[i+(j*width)] >> 5);
			   b = BLUE_OF(_acgraphH2[i+(j*width)]);
			   surface2[j*width+i]=(RGB2COLOR(r,g,b));
		   } else {
			   r = RED_OF(_acgraphH[i+(j*width)] >> 11);
			   g = GREEN_OF(_acgraphH[i+(j*width)] >> 5);
			   b = BLUE_OF(_acgraphH[i+(j*width)]);
			   surface[j*width+i]=(RGB2COLOR(r,g,b));
		   }
		   //gwinDrawPixel(pixmap,i, j);
	   }
	}
	//gwinBlitArea(gh, 0,0, width, height, 0,0, width, surface);
	//gh->color=oldColor;
	gwinRedraw(gh);
}
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

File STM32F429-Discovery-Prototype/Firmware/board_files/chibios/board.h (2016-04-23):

/*
    ChibiOS - Copyright (C) 2006..2015 Giovanni Di Sirio

    Licensed under the Apache License, Version 2.0 (the "License");
    you may not use this file except in compliance with the License.
    You may obtain a copy of the License at

        http://www.apache.org/licenses/LICENSE-2.0

    Unless required by applicable law or agreed to in writing, software
    distributed under the License is distributed on an "AS IS" BASIS,
    WITHOUT WARRANTIES OR CONDITIONS OF ANY KIND, either express or implied.
    See the License for the specific language governing permissions and
    limitations under the License.
*/

#ifndef _BOARD_H_
#define _BOARD_H_

/*
 * Setup for STMicroelectronics STM32F429I-Discovery board.
 */

/*
 * Board identifier.
 */
#define BOARD_ST_STM32F429I_DISCOVERY
#define BOARD_NAME                  "STMicroelectronics STM32F429I-Discovery"

/*
 * Board oscillators-related settings.
 * NOTE: LSE not fitted.
 */
#if !defined(STM32_LSECLK)
#define STM32_LSECLK                0U
#endif

#if !defined(STM32_HSECLK)
#define STM32_HSECLK                8000000U
#endif

/*
 * Board voltages.
 * Required for performance limits calculation.
 */
#define STM32_VDD                   300U

/*
 * MCU type as defined in the ST header.
 */
#define STM32F429xx

/*
 * IO pins assignments.
 */
#define GPIOA_BUTTON                0U
#define GPIOA_MEMS_INT1             1U
#define GPIOA_MEMS_INT2             2U
#define GPIOA_LCD_B5                3U
#define GPIOA_LCD_VSYNC             4U
#define GPIOA_PIN5                  5U
#define GPIOA_LCD_G2                6U
#define GPIOA_ACP_RST               7U
#define GPIOA_I2C3_SCL              8U
#define GPIOA_UART_TX               9U
#define GPIOA_UART_RX               10U
#define GPIOA_LCD_R4                11U
#define GPIOA_LCD_R5                12U
#define GPIOA_SWDIO                 13U
#define GPIOA_SWCLK                 14U
#define GPIOA_TP_INT                15U

#define GPIOB_LCD_R3                0U
#define GPIOB_LCD_R6                1U
#define GPIOB_BOOT1                 2U
#define GPIOB_SWO                   3U
#define GPIOB_PIN4                  4U
#define GPIOB_FMC_SDCKE1            5U
#define GPIOB_FMC_SDNE1             6U
#define GPIOB_PIN7                  7U
#define GPIOB_LCD_B6                8U
#define GPIOB_LCD_B7                9U
#define GPIOB_LCD_G4                10U
#define GPIOB_LCD_G5                11U
#define GPIOB_OTG_HS_ID             12U
#define GPIOB_OTG_HS_VBUS           13U
#define GPIOB_OTG_HS_DM             14U
#define GPIOB_OTG_HS_DP             15U

#define GPIOC_FMC_SDNWE             0U
#define GPIOC_SPI5_MEMS_CS          1U
#define GPIOC_SPI5_LCD_CS           2U
#define GPIOC_PIN3                  3U
#define GPIOC_OTG_HS_PSO            4U
#define GPIOC_OTG_HS_OC             5U
#define GPIOC_LCD_HSYNC             6U
#define GPIOC_LCD_G6                7U
#define GPIOC_PIN8                  8U
#define GPIOC_I2C3_SDA              9U
#define GPIOC_LCD_R2                10U
#define GPIOC_PIN11                 11U
#define GPIOC_PIN12                 12U
#define GPIOC_PIN13                 13U
#define GPIOC_OSC32_IN              14U
#define GPIOC_OSC32_OUT             15U

#define GPIOD_FMC_D2                0U
#define GPIOD_FMC_D3                1U
#define GPIOD_PIN2                  2U
#define GPIOD_LCD_G7                3U
#define GPIOD_PIN4                  4U
#define GPIOD_PIN5                  5U
#define GPIOD_LCD_B2                6U
#define GPIOD_PIN7                  7U
#define GPIOD_FMC_D13               8U
#define GPIOD_FMC_D14               9U
#define GPIOD_FMC_D15               10U
#define GPIOD_LCD_TE                11U
#define GPIOD_LCD_RDX               12U
#define GPIOD_LCD_WRX               13U
#define GPIOD_FMC_D0                14U
#define GPIOD_FMC_D1                15U

#define GPIOE_FMC_NBL0              0U
#define GPIOE_FMC_NBL1              1U
#define GPIOE_PIN2                  2U
#define GPIOE_PIN3                  3U
#define GPIOE_PIN4                  4U
#define GPIOE_PIN5                  5U
#define GPIOE_PIN6                  6U
#define GPIOE_FMC_D4                7U
#define GPIOE_FMC_D5                8U
#define GPIOE_FMC_D6                9U
#define GPIOE_FMC_D7                10U
#define GPIOE_FMC_D8                11U
#define GPIOE_FMC_D9                12U
#define GPIOE_FMC_D10               13U
#define GPIOE_FMC_D11               14U
#define GPIOE_FMC_D12               15U
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

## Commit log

2016-04-23 Added hardware eagle and images files
    [USB_Tester_STM32F429-DISC1.brd, USB_Tester_STM32F429-DISC1.sch]
2017-03-25 Initial BSP
    For testing only.
    [arduino_zero.cfg]

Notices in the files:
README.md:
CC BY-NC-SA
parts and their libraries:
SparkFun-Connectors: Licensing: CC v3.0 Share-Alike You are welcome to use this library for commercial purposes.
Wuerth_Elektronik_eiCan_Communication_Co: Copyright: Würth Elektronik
